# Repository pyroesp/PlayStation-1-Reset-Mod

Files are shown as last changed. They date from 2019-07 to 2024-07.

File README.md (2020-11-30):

# PlayStation 1 Reset Mod  

PlayStation 1 controller combination reset mod.  
This mod when installed, allows you to reset your PlayStation through a button combination on the controller port 1.  

**Checkout the Wiki for more information.**

Disclaimer
----------  
Anyone contributing to this mod is in no way responsible to whatever happens to your PlayStation 1 after installing or removing it.  
You do this at your own risk.  
If you don't know what you're doing, go to someone that does.   

Do **NOT** reset whilst you're saving data. If you do, you'll most likely corrupt your game save and/or your memory card.  
You have been warned.    

Why
-------
Because I have a PSIO from Cybdyn System and there's no way to change games or get back into the PSIO menu system without resetting the PlayStation.  

Versions
--------

* V1.2: Added support for the xStation reset (long reset pulse)  
* V1.1: Fixed incorrect I/O  
* V1.0: First release  

How does it work
----------------
The PlayStation sends commands to the controller and the controller responds with the status of the buttons and joysticks.  
The command and data is read by the microcontroller and after some checks to see if the button combo has been pressed, it will reset the PlayStation.  
The communication is almost exactly like SPI, which is why I'm using it in the later versions of the mod.  

The button combination for the controllers is:  
- L2 + R2 + SELECT + START, for a short reset pulse  
- L2 + R2 + SELECT + CROSS, for a long reset pulse, since V1.2  

The lightgun combination is:
- A + B + TRIGGER, for a long reset pulse 

\***Note:** My mod is connected to controller port 1, but it can be adapted to also work with port 2.  

Tests
----- 
I have successfully tested this with a digital controller, a GUNCON and an analog controller.  

Schematic and PCB
-----------------
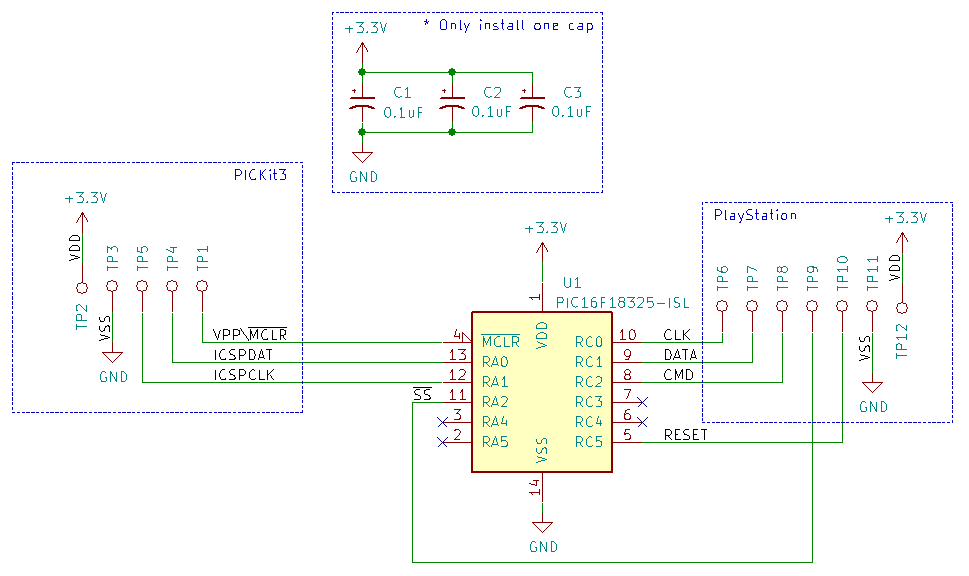
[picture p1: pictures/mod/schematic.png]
schematic
  

PCB is 14.5mm x 12mm, see images below.  
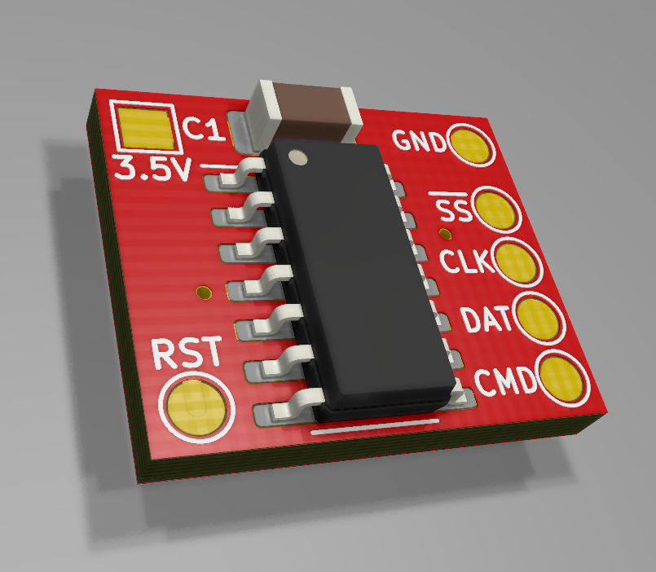
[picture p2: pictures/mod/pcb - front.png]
pcb front
  
 
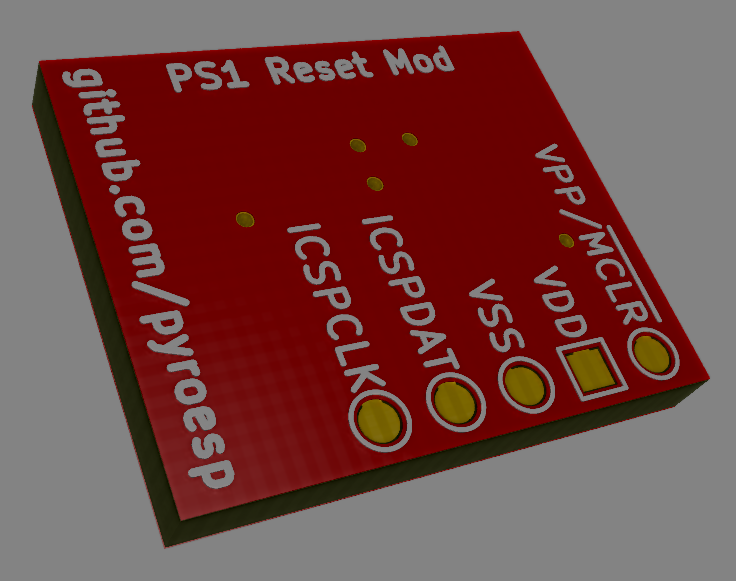
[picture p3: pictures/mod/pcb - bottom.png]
pcb back
  
You can choose from three different cap sizes: 1206, 0805 and 0603.

Parts list
----------
Only two components needed for this mod: the microcontroller and **one** capacitor.  
\***Note:** Digikey links are for reference. Go to your electronics supplier of choice.  
1x [16F18325; 14-SOIC package](https://www.digikey.be/product-detail/en/microchip-technology/PIC16F18325-I-SL/PIC16F18325-I-SL-ND/5323625)  
1x [0.1µF 16V; 1206](https://www.digikey.be/product-detail/en/w-rth-elektronik/885012208030/732-8097-1-ND/5454724) **or** [0.1µF 16V; 0805](https://www.digikey.be/product-detail/en/w-rth-elektronik/885012207045/732-8045-1-ND/5454672) **or** [0.1µF 16V; 0603](https://www.digikey.be/product-detail/en/samsung-electro-mechanics/CL10B104KO8NNNC/1276-1005-1-ND/3889091) package  

\***Note:** Capacitor smd sizes:
* 1206 = 0.125 in × 0.06 in | 3.2 mm × 1.6 mm  
* 0805 = 0.080 in × 0.05 in | 2.0 mm × 1.25 mm
* 0603 = 0.060 in × 0.03 in | 1.6 mm × 0.8 mm

If you don't have a lot of experience soldering I recommend going for the 1206.

Youtube
-------
Proof of concept of the first version: https://www.youtube.com/watch?v=H-n-7R_S09U  
Final proof of concept of the first version: https://www.youtube.com/watch?v=lb_uCGyv6pY  

See also [an 8 part video playlist](https://www.youtube.com/playlist?list=PLGaX4WJGgdHiliTw9mCHme-9vNLV6fG6E) where I go from the Arduino Nano to a PIC16F18325 and a schematic with PCB.  

Three controllers programmed  
----------------------------
Digital, Analog and GUNCON controllers have been programmed.  

/* Controller ID */  
#define ID_DIG_CTRL 0x5A41 // digital  
#define ID_ANP_CTRL 0x5A73 // analog/pad  
#define ID_ANS_CTRL 0x5A53 // analog/stick  
#define ID_GUNCON_CTRL 0x5A63 // light gun  

License
-------
Attribution-ShareAlike 4.0 International, see license file for more info

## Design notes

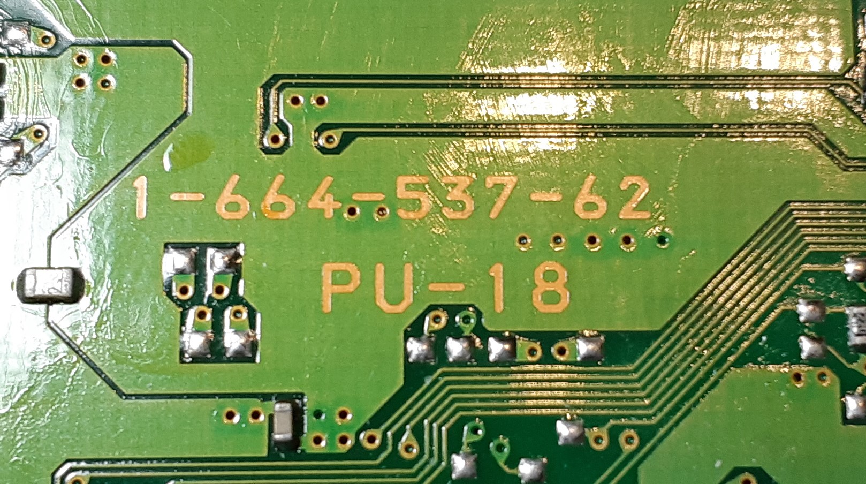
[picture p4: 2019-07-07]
pictures/motherboard/motherboard model.jpg

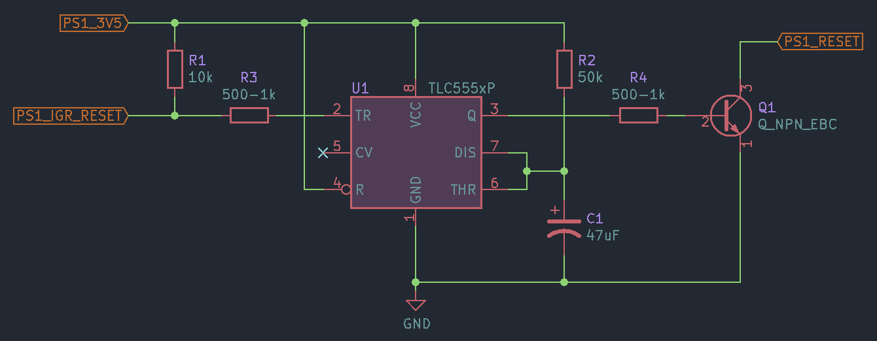
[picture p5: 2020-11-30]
pictures/pulse extender/pulse extender.PNG

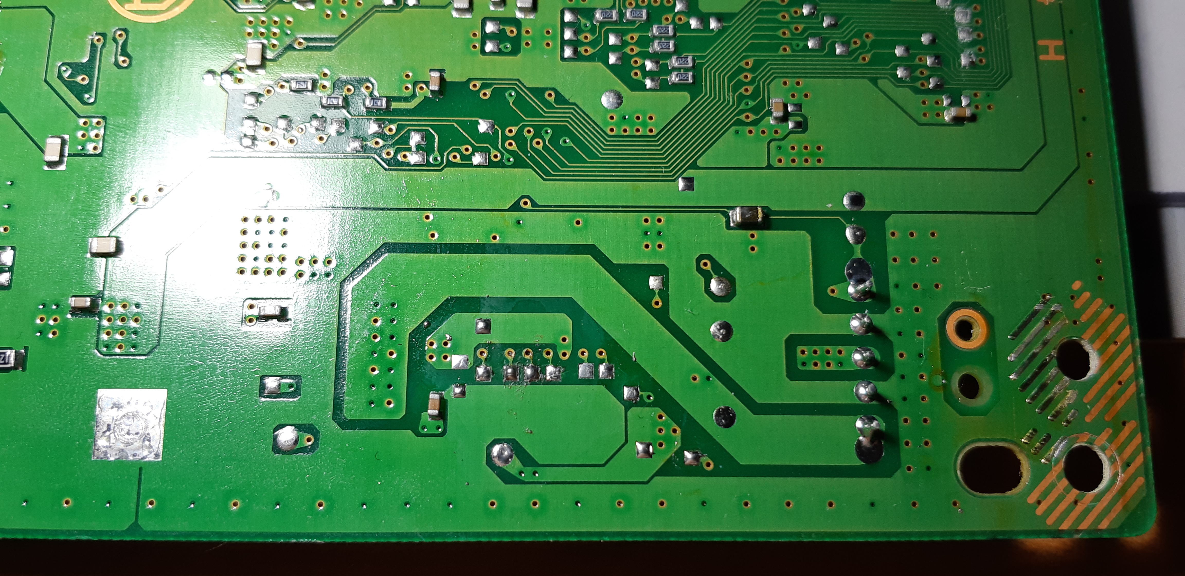
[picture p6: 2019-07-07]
pictures/motherboard/controller connection.jpg

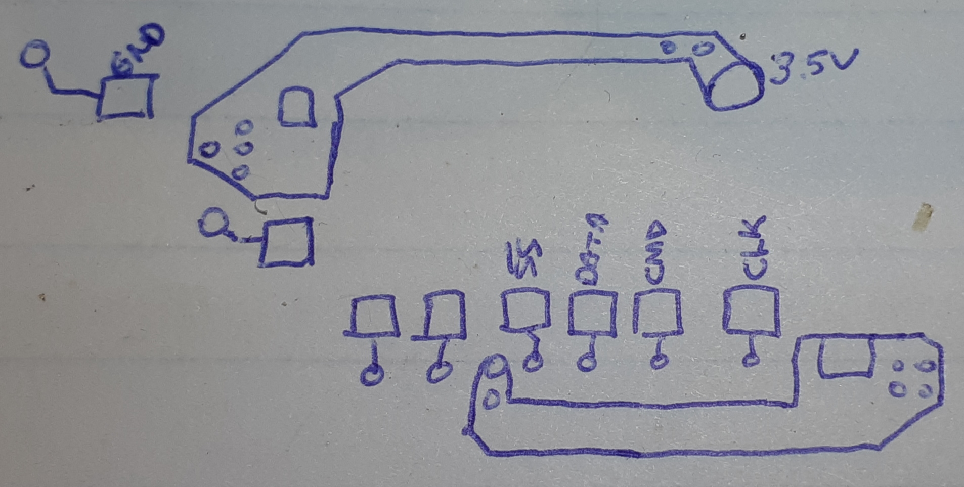
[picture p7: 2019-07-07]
pictures/motherboard/controller connection 2.jpg

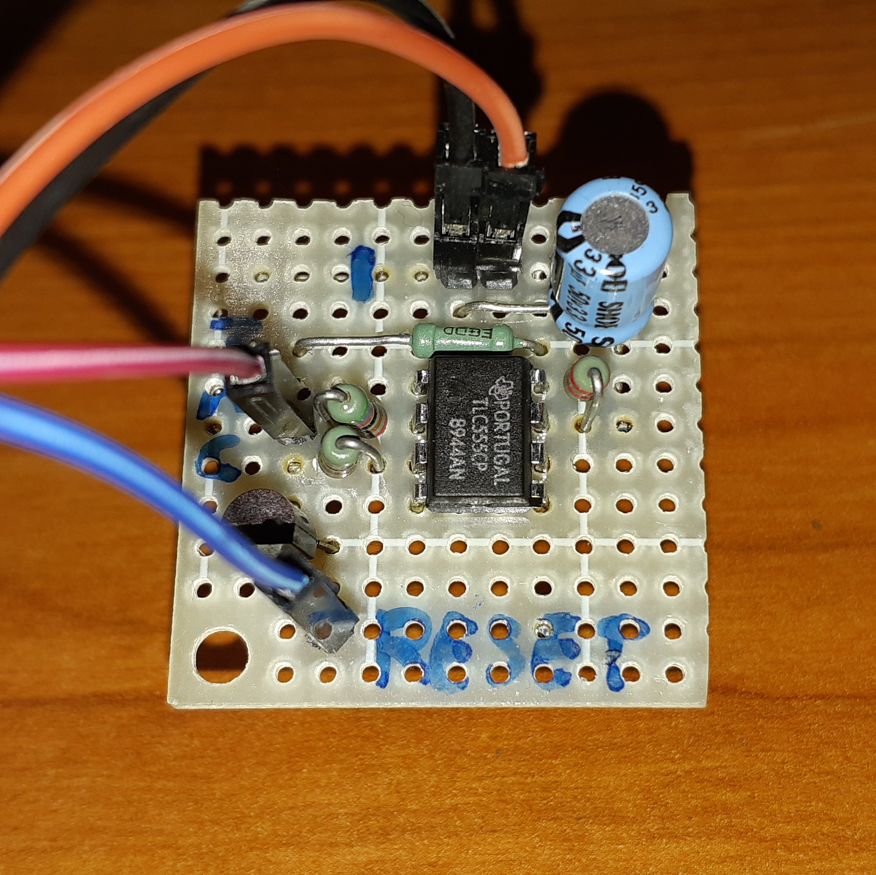
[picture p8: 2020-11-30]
pictures/pulse extender/pulse extender pcb.jpg

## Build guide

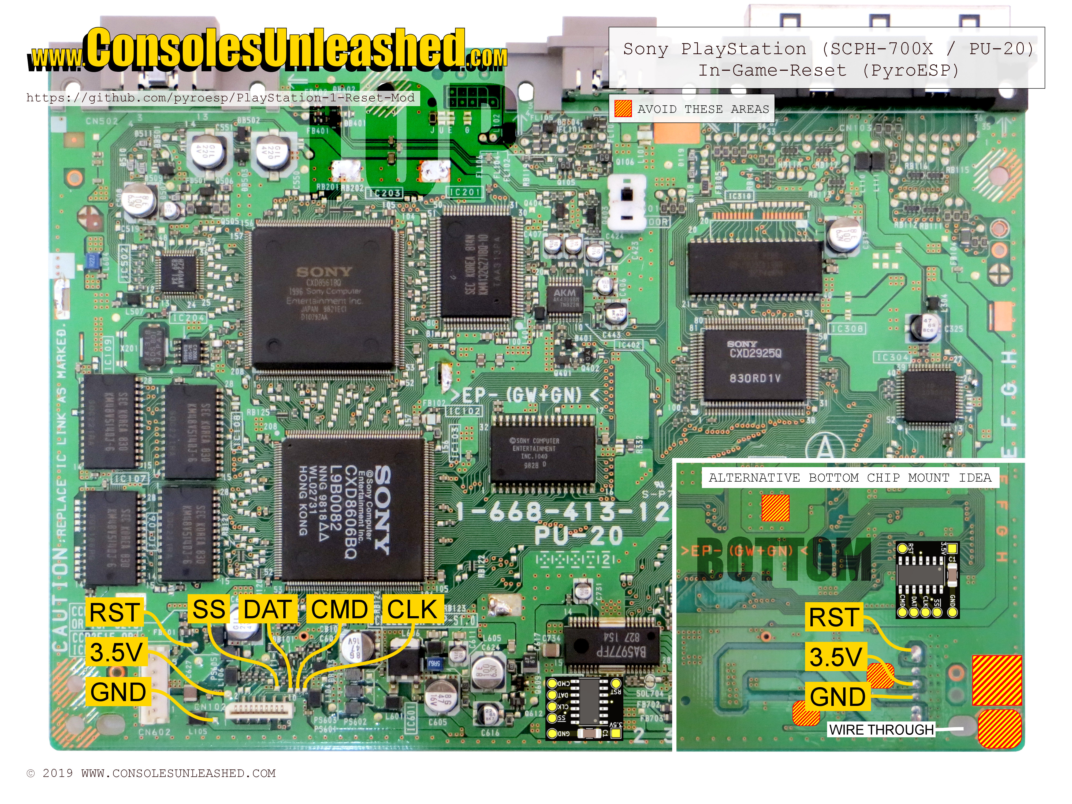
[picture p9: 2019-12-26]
pictures/guide/playstation-igr-scph-700x-pu-20.jpg

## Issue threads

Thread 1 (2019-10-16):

PCB cap and res

pyroesp, 2019-10-16:
There's no silkscreen for either the cap or resistor.
Board is small but there should be a distinction between the cap and the res otherwise people might solder the cap where the res should go.

pyroesp, 2019-10-18:
See also issue #5
Might be able to remove the resistor due to internal pull-up.

pyroesp, 2019-10-19:
fix_pcb branch fixes this issue

Closed 2019-10-19.

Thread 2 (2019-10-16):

Cosmetic change of ICSP GND to VSS

pyroesp, 2019-10-16:
Change ICSP GND silkscreen to VSS to match the schematic and the PICKit 3 pinouts.

pyroesp, 2019-10-19:
fix_pcb branch fixes this issue

Closed 2019-10-19.

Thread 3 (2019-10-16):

Add PlayStation label to schematic

pyroesp, 2019-10-16:
The PICKit 3 rectangle has a label PICKit3.
Do the same for the PlayStation connections.

pyroesp, 2019-10-19:
fix_pcb branch fixes this issue

Closed 2019-10-19.

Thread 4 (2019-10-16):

Guide to know where to solder each point

pyroesp, 2019-10-16:
At the moment, the only guide there is is in the pictures folder and is for a PU-18 motherboard.

Either make a guide for :
- Where to solder on all different PlayStation 1 motherboards.
- How to find the location to solder the mod onto.

**1st option:**
- Clear location with pictures of all different boards
- Need outside help or donor boards to get this

**2nd option:**
- Very basic multimeter skill necessary
- No need for outside help or donor boards
- Prone to user error

pyroesp, 2019-10-16:
From the 2nd option and outside help, option 1 could be made...

pyroesp, 2019-10-16:
For option 1, pictures and annotation of solder points are needed for following motherboards:
- PU-7
- PU-8
- PU-18
- PU-16
- PU-20
- PU-22
- PU-23 ?

Damn-Deal-Done, 2019-11-25:
Hello.

I have made guides for all these now (PU-8/PU-18/PU-20/PU-22). Easy to follow high resolution images. I worked most of today taking apart my PlayStations, taking high resolution photos, and probing with my multimeter. I just want to neaten up the images and I can share them with you. Probably tomorrow.

Is your board layout finalised now?

Are you able to release a Hex with all the fuses pre-programmed for programmers like the TL866?

Would it be possible for you to send me a board for testing?

Much appreciated.

Damn-Deal-Done, 2019-11-26:
Hi.

I have uploaded them to my Github. https://github.com/Damn-Deal-Done/playstation-in-game-reset-solder-points

They have my branding. Let me know if you want some without.

Not tested the guides, but all the points have continuity to the correct controller pins.

I can get a few made and test all these installs, but only once your board is finalised.

Cheers

pyroesp, 2019-11-28:
Those look really good! Awesome, thanks!
I'll make a copy off the images to put in my repository, so I have them too.
I'll have to add Credits to my readme :D
Will do this later today.

Thanks again.

Damn-Deal-Done, 2019-11-28:
No problem. I can do PU-23 later today. I don't have PU-7 or PU-16 but will do them if they cross my path for an install.

Once the chips arrive in a week or two, I will test and work out the best placement for the modboard and update the images.

Got my PICkit4 coming today.

pyroesp, 2019-11-28:
I have a PICKit3 but it shouldn't be too different than a PICKit4 so if you need any help with it, you can PM me on twitter over the weekend or in the evening in the week and I'll help you get setup.

Damn-Deal-Done, 2019-11-28:
Cheers. I think I managed.

Installed MPLAB X IPE and everything was straight forward.

Programmed the chip in an adapter plugged into a breadboard. Powered chip with the PICkit4. It was detected, successfully programmed and verified. :)

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

hurda, 2020-04-24:
I made a guide for PU-23 using a service-manual, but the mainboard-pics I used are from Wikipedia.
https://commons.wikimedia.org/wiki/File:Sony_Playstation_1_SCPH-9002_motherboard_top.jpg
https://commons.wikimedia.org/wiki/File:Sony_Playstation_1_SCPH-9002_motherboard_bottom.jpg
I don't know how to properly follow the requirements of the CC-license there.

pyroesp, 2020-04-24:
Hey thanks for that, no worries.
I know this mod works on all PS1 but I don't know if it's really useful to have it on a PS1 that doesn't have a parallel port / PSIO device.

If you want to post the pictures, add a link to CC BY-SA 4.0 license, say it's from wikipedia and add the link to the wiki images. I think you also want to say you modified the image.
That's pretty much it I think.

Damn-Deal-Done, 2020-04-24:
I made a PU-23 a few months ago. Just uploaded it. By all means make one if you still want. But mine is here and it matches the others. https://github.com/Damn-Deal-Done/playstation-in-game-reset-solder-points. No license needed.

Handy for rage quitters. :)

Cheers

hurda, 2020-04-25:
> I made a PU-23 guide a few months ago. Just uploaded it. By all means make one if you still want. But mine is here and it matches the others. https://github.com/Damn-Deal-Done/playstation-in-game-reset-solder-points. No license needed.

Ok, yours is better. :)
Except for one thing: There's a nice soldering-testpoint for DAT just below the controller-connector left of the "CN102"-marking. The rightmost one in the group of three.
Or at least that one should be for DAT according to the service-manual.

Damn-Deal-Done, 2020-04-25:
Cheers. Will have a look. I checked them all for continuity, but I have the most garbage multimeter imaginable.

Damn-Deal-Done, 2020-04-27:
Cheers, that was correct. Image is now updated using the test point for DAT. I am officially blaming my tools.

hurda, 2020-04-28:
You uploaded the old image again. ;)

Damn-Deal-Done, 2020-04-28:
That is correct. I need to start getting more sleep. Reuploaded.

pyroesp, 2020-12-21:
PU-23 has been added, finally.

Closed 2020-12-29.

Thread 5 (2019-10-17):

Pull-up resistor on MCLR needed ?

pyroesp, 2019-10-17:
From chapter 12.2.7 WEAK PULL-UP CONTROL in the 16F18325:
> PORTA pin RA3 includes the MCLR/VPP input. The
MCLR input allows the device to be reset, and can be
disabled by the MCLRE bit of Configuration Word 2. A
weak pull-up is present on the RA3 port pin. This weak
pull-up is enabled when MCLR is enabled (MCLRE = 1)
or the WPUA3 bit is set.

Is the external pull-up needed for PICKit3?
If not, then remove resistor.

pyroesp, 2019-10-19:
Removed the pull-up resistor from the breadboard this morning and everything seems to be working fine.
Once the resistor is out of the schematic and pcb, this issue can be closed.

pyroesp, 2019-10-19:
fix_pcb branch fixes this issue

Closed 2019-10-19.

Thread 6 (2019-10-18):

Printing PCB

ijacquez, 2019-10-18:
Would these be the right options to print a few PCBs?

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

Attached is the [GERBER files](https://github.com/pyroesp/PlayStation-1-Reset-Mod/files/3745094/GERBER.zip).

pyroesp, 2019-10-19:
I don't have all those options when I go for the PCB prototype quote.

This is what I'm going for :
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

pyroesp, 2019-10-19:
Make sure you get the latest version which will hide the JLCPCB order number.
Also, the resistor is gone as it's not needed due to internal pull-up, see #5 .

ijacquez, 2019-10-20:
Thanks, I'll update.

The 3.5V has changed as well. Will a part list be given as well?

pyroesp, 2019-10-20:
I'll either add the part list to the readme or add it to a wiki.

pyroesp, 2019-10-20:
I've added a part list to the readme after the schematic and pcb images.

You need anything else ?

ijacquez, 2019-10-20:
Thank you. I'll order a batch and make a few to test them out.

I guess for future revisions, it would be nice to have a connector of sorts for the PICkit3

I'll have to see what motherboard I have.

I have a PS3 to PSX adapter, so I'll see if it works.

Thanks.

pyroesp, 2019-10-20:
@ijacquez : A connector would add cost for a one time thing.
Best way I see how to do it is make your own cable with pogo pins, that's how I'm going to make it.

If the PS3 controller works on the PS1 with that adapter, then that adapter must be "translating" the communication to the PS1 protocol, which means that it should work if the device ID is one of the three programmed in the code.

ijacquez, 2019-11-10:
Got the PCB, soldered the chip, the cap.

Programming required that I power it through USB (v2.3). That threw me for a loop. I can only at this point erase, program, check blank, and verify. All passed.

What is a good way to test this without directly connecting to the PlayStation?

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

pyroesp, 2019-11-12:
Yes for programming, you need to supply the board with voltage.
You'd do that from the pickit 3 programming menu. Probably something I need to add to the readme!

If you want to test the board I would suggest making a test program for it.
There is no way to test the board out of the PlayStation unfortunately.

ijacquez, 2019-11-12:
I have made a fairly big mistake with programming the chip.

So when the board needs to be supplied with voltage, does that mean I simply connect the PICkit3's VPP to VDD, then within the programming menu, have the PICkit3 supply the voltage, and set the voltage to ~2.5V?

pyroesp, 2019-11-14:
No, the VPP of the PICKit3 goes to the VPP/MCLR pin on the back. VPP outputs a higher voltage than VDD when programming, which potentially could damage the PIC microcontroller!

The silkscreen on the back should mention this :
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

In the advanced mode of MPLAB IPE go to the Power tab. These are my parameters for the 16F18325:
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
These parameters should have a default value for the 16F18325, but the thing you might have to check is the usage of high voltage programming and also that checkbox for powering the target with the PICKit3.
The VDD voltage can be either 5V or 3.5V, it doesn't really matter as long as you're programming the PIC when it's not connected to the PlayStation.

Once it is programmed and verified by MPLAB IPE, then you only need to install it in the PlayStation.

pyroesp, 2019-12-14:
@ijacquez hello, just letting you know that there's a new firmware version available.
https://github.com/pyroesp/PlayStation-1-Reset-Mod/releases/tag/v1.1

There was an error while making the PCB where data and cmd were switched. The new firmware fixes this.
Gerber files are still the same as in v1.0

ijacquez, 2019-12-15:
Thanks for the heads up. I'll give the project another whirl.

pyroesp, 2020-02-14:
Since there's nothing new here I'll close this issue.

Closed 2020-02-14.

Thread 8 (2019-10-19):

Hide JLCPCB order number

pyroesp, 2019-10-19:
JLCPCB puts the order number on the PCB. There's no way around that. Find a place to hide it if possible.

pyroesp, 2019-10-19:
You can specify the location of the jlcpcb order by adding JLCJLCJLCJLC somewhere on the silkscreen.
I've added it underneath the microcontroller so that it is hidden.

Commit 2d62dcc updated the pcb and gerber files.

Closed 2019-10-19.

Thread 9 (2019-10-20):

Code clean-up

pyroesp, 2019-10-20:
Clean up the code for first release:
- Add a debug define for uart debugging
- remove RA4 and RA5 pin toggle
- move functions below main and add function prototypes
- fix tab/space indents

pyroesp, 2019-10-20:
Commit 7637368 fixed the code for a first release

Closed 2019-10-20.

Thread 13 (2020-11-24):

Alternative button-combo for longer reset

ArcadeTV, 2020-11-24:
Thank you very much for this great project, great documentation and dedication to this!

I would like to suggest adding a second button-combo to the code, which when triggered holds the reset for appx. 2 seconds.
The reason for this is the release of the X-Station optical drive emulator, which is responding to the longer reset and returning to the menu instead of resetting the game. There's a IGR for the snes which works as described when using an sd2snes/fxPAKpro.

pyroesp, 2020-11-24:
Looking at the xStation doc it looks like it needs "about 3 seconds" to go back to the menu.
I could definitely add something like that.

ArcadeTV, 2020-11-25:
On the SNES the IGR uses a similar combo:
(https://github.com/borti4938/SNES_MultiRegion_with_DeJitter_QID)

simple reset: L + R + Select + Start
double reset (back to main menu of sd2snes): L + R + Select + X

Since the layout of the PS1 controller is similar to the snes, I'd suggest this combo for the change.

Thank you very much for even considering adding this, it's very much appreciated!

pyroesp, 2020-11-25:
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
Yeah, I was thinking about using the x button too, instead of START, for the longer reset.
Press x for xStation reset. It's the perfect button for it.

> Thank you very much for even considering adding this, it's very much appreciated!
No worries! When I talked about the xStation online and compatibility with my mod, people told me that they'd most likely also buy the PS1Digital so mine wouldn't be needed.
From then on I never really paid much more attention to this, but I'm not against adding features like this to the mod.

It only takes a minute to change the code, but I'll have to test this to see if it works as intended.
Hopefully I can spare some time to do this this weekend.

If not then you'll see it when I close this issue and/or post about it online.

ArcadeTV, 2020-11-25:
No stress, take your time. I can test too once you pushed the changes. I might have a PIC16F18325 laying around.
Thank you very much again for this!

pyroesp, 2020-11-30:
After a bit of testing I've commited the new code for the PIC microcontroller.
The xStation should be supported now.

492eb7d

Damn-Deal-Done, 2020-11-30:
ArcadeTV if you want to test a board with the new firmware just let me know and I can send you one for free. It's not a problem.

ArcadeTV, 2020-11-30:
> ArcadeTV if you want to test a board with the new firmware just let me know and I can send you one for free. It's not a problem.

That's so nice, thank you! I have a breakout board for testing, also ordered a pcb with my latest jlcpcb order ;-)

Closed 2020-11-30.

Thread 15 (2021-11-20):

Programing the PIC16F18325

mroy1300, 2021-11-20:
Hello,

I'm trying to program the PIC16F18325 with the supplied hex file but when I read the device memory the hex that gets output is different from the original. Am I doing something wrong? How are you supposed to verify that the chip was successfully programed?

My apologies if this is not the best place to post this but I didn't know where else to do it.

Let me know if you need any additional info, I didn't know what info I should supply.

pyroesp, 2021-11-21:
It should be identical to the hex. I'm not doing anything fancy to program it.
You can check the "how to" in the wiki.

Also try another 16F18325 just in case that one is doing weird things.

mroy1300, 2021-11-21:
I have been doing more testing and I found that a fresh non-programed chip output the same hex file as a programed chip. I'm wondering if the programmer is either not programing the chip or if I'm reading the hex file wrong.

I have attached pictures of the chip, board, and programer. The VDD, VPP, CLK, VSS, and DAT pads are out of order on the board so I made a jumper to correct that.

I also took a video of the process. It looks like the hex file is not being written to the chip. I'm pretty good with computers but this is my first attempt at programing microchips. Hopefully I'm just doing something wrong.

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

https://user-images.githubusercontent.com/94731368/142781816-cbd6bbb6-b071-4ef7-b262-45f8858fef55.mp4

pyroesp, 2021-11-22:
When programming through IPE, you can see the output saying "Program/Verify completed". Which means it's programmed and verified the contents of the chip.
If you want to read the data back, you can just click on the read button instead of going to the IDE.

Also, you are selecting EE/Flash data instead of device memory in the IDE.

mroy1300, 2021-11-22:
I see the log saying it's verified but the hex doesn't change. I have read Device memory through IDE also but I get a huge hex file with 1061 lines so I figured that was reading the memory from the programmer.

When I read through the IPE I don't get any output besides the IPE saying it was read. DO I need to turn on logging?
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

My apologies, I assume I'm doing something wrong. I just can't figure it out.

mroy1300, 2021-11-23:
OK, I have it so that I can read and export the hex file in IPE. When I program the chip everything looks right and I even ran a blank check on the chip. The program confirmed that the chip is not blank but when I read the hex file it has not changed. I also confirmed that the board does not work when installed into the PS1. I'm at a loss at this point. Everything seems like it should be working.

pyroesp, 2021-11-23:
I suggest you try programming a blinky LED to another microcontroller to see if your setup works.

Closed 2021-12-04.

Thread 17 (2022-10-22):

WTF???

orabeidm, 2022-10-22:
i ordered 2 controllers, my friend flashed them and i installed them in pu22 - none work. Next, I decided to make a mod using arduino, but the code presented here is not for the Arduino IDE. OK. trying to build it with avr toolchain and then flash it with avrdude - not going to. in the code there is a call to the port, which is not physically present in MK 328p. in 328p there are pins that sit on ports B, C and D, and in the source there is a setting for port E pins.

wtf???

is it working at all? is there any way to make this work? I have no way to buy a ready-made mod. there is no delivery to my country.

orabeidm, 2022-10-22:
I'm stupid, I mixed up the wires

Closed 2022-10-22.

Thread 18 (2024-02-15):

IGR for both Controller Ports

GeAd23, 2024-02-15:
Is it possible to use two IGR boards for Controller 1 and 2. How can I do this ? (Modchip is installed too)

I would use one igr from (flat) unleashedmods and a normal igr board.

Yours Sincerely

pyroesp, 2024-02-19:
Hi sorry for the late reply.
Each port has it's own ATT (or SS) signal as seen here on port 1:
https://raw.githubusercontent.com/pyroesp/PlayStation-1-Reset-Mod/master/pictures/guide/playstation-controller-pin-map.jpg

IGR1 should connect to ATT1 and IGR2 should connect to ATT2 if I'm not mistaken.

GeAd23, 2024-02-19:
Okay. Thank you. The other ports are connected together Else SS ? Like SPI work.
I would test it out.

Yours Sincerely

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

Closed 2024-02-21.

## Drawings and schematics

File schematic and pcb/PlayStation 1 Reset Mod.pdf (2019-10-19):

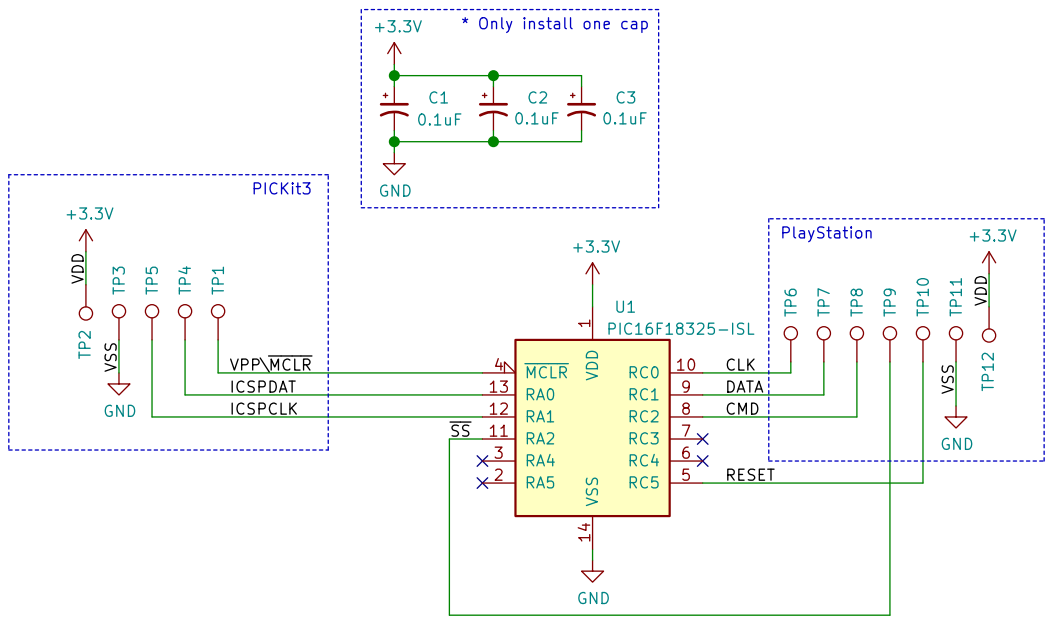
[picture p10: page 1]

* Only install one cap
+3.3V GND

File: PlayStation 1 Reset Mod.sch Sheet: /
Id: 1/1 Title:

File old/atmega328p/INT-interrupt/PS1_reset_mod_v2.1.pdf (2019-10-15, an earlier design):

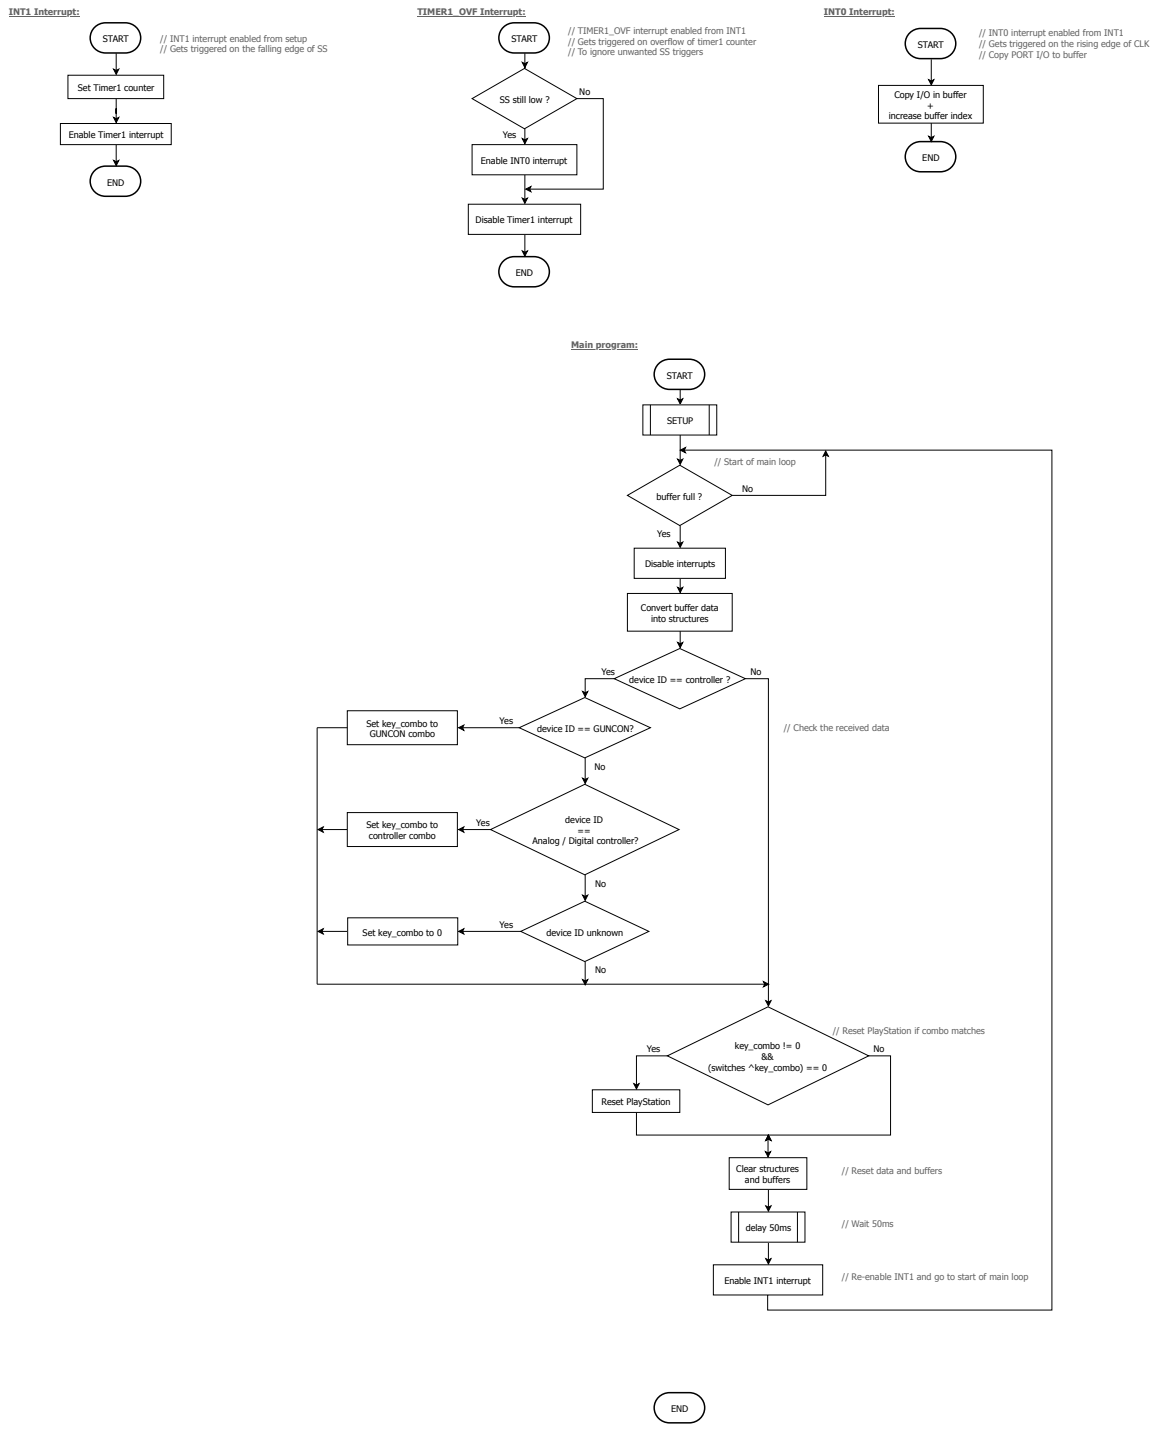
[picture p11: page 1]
START; END; Enable Timer1 interrupt; SETUP; buffer full ?; Disable interrupts; device ID ==; Set key_combo to GUNCON combo; Set key_combo to controller combo; Set key_combo to 0; key_combo != 0 && (switches ^key_combo) == 0; Reset PlayStation; Clear structures and buffers; Yes; // Wait 50ms; delay 50ms; INT1 Interrupt:; INT0 Interrupt:; Main program:; Enable INT0 interrupt; TIMER1_OVF Interrupt:; Set Timer1 counter; Disable Timer1 interrupt

// INT1 interrupt enabled from setup
// Gets triggered on the falling edge of SS

// TIMER1_OVF interrupt enabled from INT1
// Gets triggered on overflow of timer1 counter
// To ignore unwanted SS triggers

// INT0 interrupt enabled from INT1
// Gets triggered on the rising edge of CLK
// Copy PORT I/O to buffer

Copy I/O in buffer

SS still low ?

increase buffer index

// Start of main loop

Convert buffer data
into structures

Yes
device ID == controller ?

device ID == GUNCON?

// Check the received data

Analog / Digital controller?

device ID unknown

// Reset PlayStation if combo matches

// Reset data and buffers

// Re-enable INT1 and go to start of main loop Enable INT1 interrupt

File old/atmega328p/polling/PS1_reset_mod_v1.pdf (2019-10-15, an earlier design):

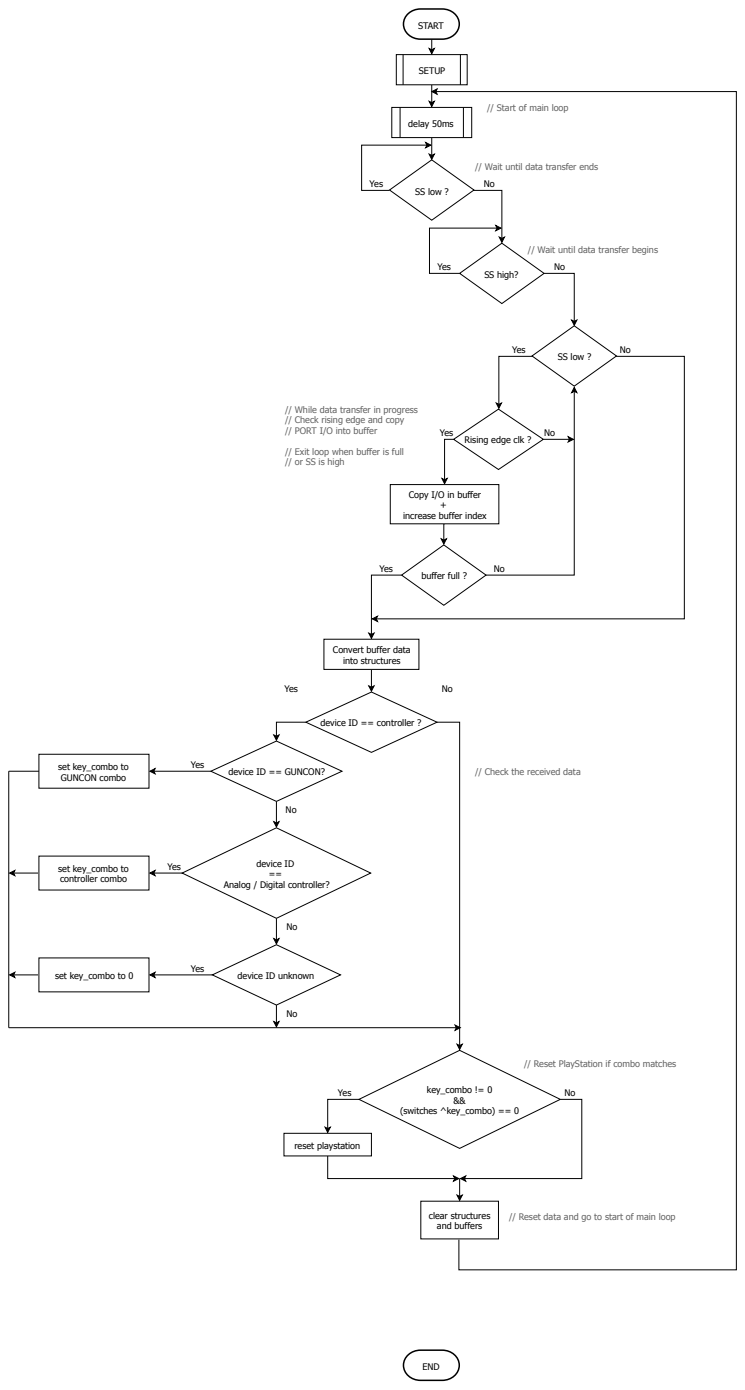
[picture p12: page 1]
START; SETUP; delay 50ms; SS low ?; Yes; SS high?; buffer full ?; device ID ==; set key_combo to GUNCON combo; set key_combo to controller combo; set key_combo to 0; key_combo != 0 && (switches ^key_combo) == 0; reset playstation; clear structures and buffers; END

// Start of main loop

// Wait until data transfer ends

// Wait until data transfer begins

// While data transfer in progress
// Check rising edge and copy
// PORT I/O into buffer

Yes
Rising edge clk ?

// Exit loop when buffer is full
// or SS is high

Copy I/O in buffer

increase buffer index

Convert buffer data
into structures

device ID == controller ?

device ID == GUNCON?

// Check the received data

Analog / Digital controller?

device ID unknown

// Reset PlayStation if combo matches

// Reset data and go to start of main loop

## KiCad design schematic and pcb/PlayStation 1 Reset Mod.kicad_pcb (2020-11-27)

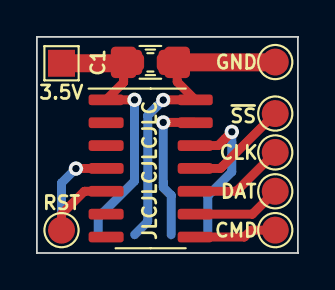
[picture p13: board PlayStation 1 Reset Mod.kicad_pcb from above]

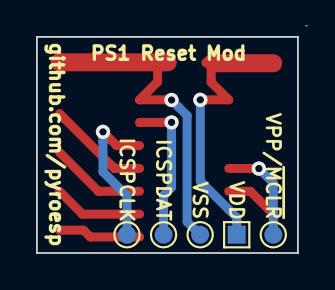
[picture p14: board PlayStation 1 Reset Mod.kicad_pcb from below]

Board: 2 copper layers, 14.5 x 12.0 mm, 15 parts (5 on the bottom side), 9 nets.

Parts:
3.5V: TestPoint; TestPoint_Pad_1.5x1.5mm
C1: 0.1uF; C_1206_3216Metric_Pad1.42x1.75mm_HandSolder
C2: 0.1uF; C_0805_2012Metric_Pad1.15x1.40mm_HandSolder
C3: 0.1uF; C_0603_1608Metric_Pad1.05x0.95mm_HandSolder
CLK: TestPoint; TestPoint_Pad_D1.5mm
CMD: TestPoint; TestPoint_Pad_D1.5mm
DAT: TestPoint; TestPoint_Pad_D1.5mm
GND: TestPoint; TestPoint_Pad_D1.5mm
ICSPCLK: TestPoint; TestPoint_Pad_D1.0mm
ICSPDAT: TestPoint; TestPoint_Pad_D1.0mm
RST: TestPoint; TestPoint_Pad_D1.5mm
U1: PIC16F18325-ISL; SOIC-14_3.9x8.7mm_P1.27mm
VDD: TestPoint; TestPoint_Pad_1.0x1.0mm
VPP/~MCLR: TestPoint; TestPoint_Pad_D1.0mm
VSS: TestPoint; TestPoint_Pad_D1.0mm

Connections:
+3V3: 3.5V.1, C1.1, C2.1, C3.1, U1.1, VDD.1
/CLK: CLK.1, U1.10
/CMD: CMD.1, U1.8
/DATA: DAT.1, U1.9
/ICSPCLK: ICSPCLK.1, U1.12
/ICSPDAT: ICSPDAT.1, U1.13
/RESET: RST.1, U1.5
/VPP\~MCLR: U1.4, VPP/~MCLR.1
GND: C1.2, C2.2, C3.2, GND.1, U1.14, VSS.1

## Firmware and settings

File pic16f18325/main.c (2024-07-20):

/*
 * File:   main.c
 * Author: pyroesp
 * 
 * PlayStation 1 Reset Mod for PIC16F18325
 *
 * Created on September 21, 2019, 5:33 PM
 
 Connection:
    RA2 = SS
    RC0 = CLK
    RC1 = DATA
    RC2 = CMD
    SDO1,2 = unassigned
    RC5 = RESET
 */


// CONFIG1
#pragma config FEXTOSC = OFF     // FEXTOSC External Oscillator mode Selection bits (HS (crystal oscillator) above 4 MHz)
#pragma config RSTOSC = HFINT32 // Power-up default value for COSC bits (HFINTOSC with 2x PLL (32MHz))
#pragma config CLKOUTEN = OFF   // Clock Out Enable bit (CLKOUT function is disabled; I/O or oscillator function on OSC2)
#pragma config CSWEN = ON       // Clock Switch Enable bit (Writing to NOSC and NDIV is allowed)
#pragma config FCMEN = OFF      // Fail-Safe Clock Monitor Enable (Fail-Safe Clock Monitor is disabled)

// CONFIG2
#pragma config MCLRE = ON       // Master Clear Enable bit (MCLR/VPP pin function is MCLR; Weak pull-up enabled)
#pragma config PWRTE = OFF      // Power-up Timer Enable bit (PWRT disabled)
#pragma config WDTE = OFF       // Watchdog Timer Enable bits (WDT disabled; SWDTEN is ignored)
#pragma config LPBOREN = OFF    // Low-power BOR enable bit (ULPBOR disabled)
#pragma config BOREN = OFF      // Brown-out Reset Enable bits (Brown-out Reset disabled)
#pragma config BORV = LOW       // Brown-out Reset Voltage selection bit (Brown-out voltage (Vbor) set to 2.45V)
#pragma config PPS1WAY = ON     // PPSLOCK bit One-Way Set Enable bit (The PPSLOCK bit can be cleared and set only once; PPS registers remain locked after one clear/set cycle)
#pragma config STVREN = OFF     // Stack Overflow/Underflow Reset Enable bit (Stack Overflow or Underflow will not cause a Reset)
#pragma config DEBUG = OFF      // Debugger enable bit (Background debugger disabled)

// CONFIG3
#pragma config WRT = OFF        // User NVM self-write protection bits (Write protection off)
#pragma config LVP = OFF        // Low Voltage Programming Enable bit (High Voltage on MCLR/VPP must be used for programming.)

// CONFIG4
#pragma config CP = OFF         // User NVM Program Memory Code Protection bit (User NVM code protection disabled)
#pragma config CPD = OFF        // Data NVM Memory Code Protection bit (Data NVM code protection disabled)

// #pragma config statements should precede project file includes.
// Use project enums instead of #define for ON and OFF.

#define _XTAL_FREQ 32000000

#include <xc.h>
#include <stdint.h>

#define _BV(b) (1<<(b))

/* Uncomment the define below to have UART TX debugging on RC3 */
//#define DEBUG

#ifdef DEBUG
#define REBOOT_DELAY 2 // s
#else
#define REBOOT_DELAY 20 // s
#endif

#define SHORT_DELAY 500 // ms
#define LONG_DELAY 2 // s

/* Reset port */
#define PS1_LAT_IO LATC // IO port reg used for RESET
#define PS1_TRIS_IO TRISC // IO dir reg used for RESET
#define PS1_RESET 5 // Only IO that outputs a logic 0

/* Controller ID */
#define ID_DIG_CTRL 0x5A41 // digital: SCPH-1080 (EU)
#define ID_ANP_CTRL 0x5A73 // analog/pad: SCPH-110 (EU)
#define ID_ANS_CTRL 0x5A53 // analog/stick: SCPH-110 (EU)
#define ID_DS2_CTRL 0x5A79 // dualshock 2
#define ID_GUNCON_CTRL 0x5A63 // light gun: NPC-103 (EU)

/* PlayStation Commands */
#define CMD_SEL_CTRL_1 0x01 // select controller 1
#define CMD_SEL_MEMC_1 0x81 // select memory card 1
#define CMD_READ_SW 0x42 // read switch status from controller

/* PlayStation Communication Buff Size */
#define PS1_CTRL_BUFF_SIZE 9 // max size of buffer needed for a controller

/* Key Combo */
#define KEY_COMBO_CTRL 0xFCF6       // select-start-L2-R2   1111 1100 1111 0110
#define KEY_COMBO_GUNCON 0x9FF7     // A-trigger-B          1001 1111 1111 0111
#define KEY_COMBO_XSTATION 0xBCFE   // select-cross-L2-R2   1011 1100 1111 1110

/*
Keys : 
    SELECT, // 0
    L3,
    R3,
    START, // light gun A
    UP,
    RIGHT,
    DOWN,
    LEFT,
    L2,
    R2,
    L1,
    R1,
    TRIANGLE,
    CIRCLE, // light gun trigger
    CROSS, // light gun B
    SQUARE
*/


/* PlayStation Controller Command Union */
union PS1_Cmd{
    uint8_t buff[PS1_CTRL_BUFF_SIZE];
    struct{
        uint8_t device_select; // 0x01 or 0x81
        uint8_t command; // 0x42 for read switch
        uint8_t unused[PS1_CTRL_BUFF_SIZE-2]; // always 0 for controller
    };
};

/* PlayStation Controller Data Union */
union PS1_Ctrl_Data{
    uint8_t buff[PS1_CTRL_BUFF_SIZE]; // buffer to read data
    struct{
        uint8_t unused; // always 0xFF
        uint16_t id; // 0x5Ayz - y = type; z = # of half word
        uint16_t switches; // controller switches
        union{
            // light gun only (8MHz clock counter since hsync)
            uint16_t x_pos; // if 0x0001 then error, check y_pos
            struct{
                uint8_t adc0; // right joy X
                uint8_t adc1; // right joy Y
            };
        };
        union{
            //light gun only (scanlines since vsync)
            uint16_t y_pos; // if x_pos = 0x0001 && y_pos = 0x000A => not aimed at screen
            struct{
                uint8_t adc2; // left joy X
                uint8_t adc3; // left joy Y
            };
        };
    };
};

/* Global variables */
volatile union PS1_Cmd cmd;
volatile union PS1_Ctrl_Data data;
volatile uint8_t cmd_cnt, data_cnt;

/* Function prototype */
void reverse_byte(uint8_t *b);
void clear_buff(uint8_t *p, uint8_t s);
void __delay_s(uint8_t s);

void reset_short(void);
void reset_long(void);

#ifdef DEBUG
void UART_init(void);
void UART_sendByte(uint8_t c);
void UART_print(uint8_t *str);
void UART_printHex(uint8_t b);
#else
#define UART_init(a)
#define UART_sendByte(a) 
#define UART_print(a) 
#define UART_printHex(a) 
#endif


/* Interrupt */
void __interrupt() _spi_int(void) {    
    // SPI1 interrupt
    if (PIR1bits.SSP1IF){
        if (data_cnt < PS1_CTRL_BUFF_SIZE){
            data.buff[data_cnt] = SSP1BUF;
            data_cnt++;
        }
        PIR1bits.SSP1IF = 0; // clear SPI1 flag
    }
    // SPI2 interrupt
    if (PIR2bits.SSP2IF){
        if (cmd_cnt < PS1_CTRL_BUFF_SIZE){
            cmd.buff[cmd_cnt] = SSP2BUF;
            cmd_cnt++;
        }
        PIR2bits.SSP2IF = 0; // clear SPI2 flag
    }
}

/* Main */
void main(void){
    uint8_t i;
    
    // SETUP I/O
    ANSELA = 0; // port A is digital IO
    LATA = 0; // clear latch A
    LATC = 0; // clear latch C
    ANSELC = 0; // port C is digital IO
    
    PS1_LAT_IO &= ~_BV(PS1_RESET); // clear reset output 
    PS1_TRIS_IO |= _BV(PS1_RESET); // set reset pin to input

    TRISAbits.TRISA2 = 1; // SS set to input
    TRISCbits.TRISC0 = 1; // SCK set to input
    TRISCbits.TRISC1 = 1; // SDI1 set to input
    TRISCbits.TRISC2 = 1; // SDI2 set to input
    
    // SETUP SPI1 & SPI2 I/O
    SSP1SSPPSbits.SSP1SSPPS = 0x02; // SS1 = RA2 
    SSP2SSPPSbits.SSP2SSPPS = 0x02; // SS2 = RA2 
    
    SSP1CLKPPSbits.SSP1CLKPPS = 0x10; // SCK1 = RC0
    SSP2CLKPPSbits.SSP2CLKPPS = 0x10; // SCK2 = RC0
    
    SSP1DATPPSbits.SSP1DATPPS = 0x11; // SDI1 = RC1 
    SSP2DATPPSbits.SSP2DATPPS = 0x12; // SDI2 = RC2 
    
    // SETUP SPI1 & SPI2
    SSP1STATbits.SMP = 0; // slave mode SPI1
    SSP1STATbits.CKE = 0; // transmit from idle to active
    SSP1CON1bits.CKP = 1; // clock idle high
    SSP1CON1bits.SSPM = 0x04; // slave mode: clk = sck pin; SS enabled
    SSP1CON3bits.BOEN = 1; // ignore BF flag
    SSP1CON1bits.SSPEN = 1; // enable SPI1
    
    SSP2STATbits.SMP = 0; // slave mode SPI2
    SSP2STATbits.CKE = 0; // transmit from idle to active
    SSP2CON1bits.CKP = 1; // clock idle = high
    SSP2CON1bits.SSPM = 0x04; // slave mode: clk = sck pin; SS enabled
    SSP2CON3bits.BOEN = 1; // ignore BF flag
    SSP2CON1bits.SSPEN = 1; // enable SPI2
    
    SSP1BUF = 0xFF;
    SSP2BUF = 0xFF;
    
    // DEBUG
    UART_init();
    UART_print((uint8_t*)"PlayStation 1 mod:\n\r");
    
    // SETUP variables and arrays
    data_cnt = 0;
    cmd_cnt = 0;
    
    clear_buff((uint8_t*)cmd.buff, PS1_CTRL_BUFF_SIZE);
    clear_buff((uint8_t*)data.buff, PS1_CTRL_BUFF_SIZE);
    
    // delay before enabling interrupts
    __delay_s(REBOOT_DELAY); // wait 20 sec before next reset
    
    // SETUP INTERRUPTS
    PIR1bits.SSP1IF = 0; // clear SPI1 flag
    PIR2bits.SSP2IF = 0; // clear SPI2 flag
    PIE1bits.SSP1IE = 1; // enable MSSP interrupt (SPI1)
    PIE2bits.SSP2IE = 1; // enable MSSP interrupt (SPI2)
       
    INTCONbits.PEIE = 1; // peripheral interrupt enable
    INTCONbits.GIE = 1; // global interrupt enable
       
    // MAIN LOOP
    for(;;){
        if (data_cnt >= PS1_CTRL_BUFF_SIZE || cmd_cnt >= PS1_CTRL_BUFF_SIZE){
            INTCONbits.PEIE = 0; // peripheral interrupt disable
            UART_print((uint8_t*)"\n\rCMD: ");
            for (i = 0; i < PS1_CTRL_BUFF_SIZE; i++){
                reverse_byte((uint8_t*)&cmd.buff[i]);
                UART_printHex((uint8_t)cmd.buff[i]);
                UART_print((uint8_t*)" ");
            }
            UART_print((uint8_t*)"\n\rDATA: ");
            for (i = 0; i < PS1_CTRL_BUFF_SIZE; i++){
                reverse_byte((uint8_t*)&data.buff[i]);
                UART_printHex((uint8_t)data.buff[i]);
                UART_print((uint8_t*)" ");
            }
            UART_print((uint8_t*)"\n\rData done converting");
            
            // Check first command for device selected
            if (cmd.device_select == CMD_SEL_CTRL_1 && cmd.command == CMD_READ_SW){
                // Check ID
                switch(data.id){
                    case ID_GUNCON_CTRL:
                        // Check switch combo
                        switch(data.switches){
                            case KEY_COMBO_GUNCON:
                                reset_long();
                                break;
                        }
                        break;
                    case ID_DIG_CTRL:
                    case ID_ANS_CTRL:
                    case ID_ANP_CTRL:
                    case ID_DS2_CTRL:
                        // Check switch combo
                        switch(data.switches){
                            case KEY_COMBO_CTRL:
                                reset_short();
                                break;
                            case KEY_COMBO_XSTATION:
                                reset_long();
                                break;
                        }
                        break;
                }
            }

            clear_buff((uint8_t*)data.buff, PS1_CTRL_BUFF_SIZE); // clear controller stuff
            clear_buff((uint8_t*)cmd.buff, PS1_CTRL_BUFF_SIZE); // clear controller stuff
    
            data_cnt = 0; // reset counters
            cmd_cnt = 0; // reset counters
            
            PIR1bits.SSP1IF = 0; // clear SPI1 flag
            PIR2bits.SSP2IF = 0; // clear SPI2 flag
            INTCONbits.PEIE = 1; // peripheral interrupt enable
        }
    }
    
    for(;;);
}

/* Reverse byte order 
 * The playstation send data LSb first,
 * but the PIC uses a shift left register
 * so the LSb from the PS1 becomes the MSb of the PIC
*/
void reverse_byte(uint8_t *b) {
   *b = (*b & 0xF0) >> 4 | (*b & 0x0F) << 4;
   *b = (*b & 0xCC) >> 2 | (*b & 0x33) << 2;
   *b = (*b & 0xAA) >> 1 | (*b & 0x55) << 1;
}

/* Clear buffer of size s, aka fill with zero */
void clear_buff(uint8_t *p, uint8_t s){
    uint8_t i;
    for (i = 0; i < s; i++)
        p[i] = 0;
}

/* delay in seconds */
void __delay_s(uint8_t s){
    for (; s > 0; s--)
        __delay_ms(1000);
}


void reset_short(void){
    UART_print((uint8_t*)"\n\rShort Reset successful\n\r");
    // change RESET pin from input to output, logic low (PORT is already 0)
    PS1_TRIS_IO &= ~_BV(PS1_RESET);
    __delay_ms(SHORT_DELAY); // hold reset for 500ms
    // change RESET back to input
    PS1_TRIS_IO |= _BV(PS1_RESET);
    // hold the mcu from resetting too early, just in case
    __delay_s(REBOOT_DELAY);
}

void reset_long(void){
    UART_print((uint8_t*)"\n\rLong Reset successful\n\r");
    // change RESET pin from input to output, logic low (PORT is already 0)
    PS1_TRIS_IO &= ~_BV(PS1_RESET);
    __delay_s(LONG_DELAY); // hold reset for 2s
    // change RESET back to input
    PS1_TRIS_IO |= _BV(PS1_RESET);
    // hold the mcu from resetting too early, just in case
    __delay_s(REBOOT_DELAY);
}

#ifdef DEBUG
/**********************************************************/
/* UART Debug Functions */

/* Initialize UART with TX on output RC3 */
void UART_init(void){
    // SETUP UART
    ANSELCbits.ANSC3 = 0; // TX set to digital I/O
    LATCbits.LATC3 = 0; // set output 0
    TRISCbits.TRISC3 = 0; // TX set to output
    RC3PPSbits.RC3PPS = 0x14; // TX = RC3

    SP1BRGL = 51; // 9615 baud
    SP1BRGH = 0; // 9615 baud
    
    TX1STAbits.SYNC = 0; // Asynch mode
    RC1STAbits.SPEN = 1; // Serial Port enable bit
    TX1STAbits.BRGH = 0; // low speed
    BAUD1CONbits.BRG16 = 0; // 8 bit baud rate
    BAUD1CONbits.SCKP = 0; // Idle state for TX high level
    CLKRCONbits.CLKRDIV = 0; // Fosc
    CLKRCONbits.CLKRDC = 2; // 50% duty cyle
    CLKRCONbits.CLKREN = 1; // Enable CLK reference
    
    TX1STAbits.TXEN = 1; // Enable transmitter  
}

/* Send byte and wait until transfer finished */
void UART_sendByte(uint8_t c){
    TX1REG = c;
    while(!TX1STAbits.TRMT);
}

/* Send string */
void UART_print(uint8_t *str){
    uint8_t i;
    for (i = 0; str[i] != 0 && i < 255; i++)
        UART_sendByte(str[i]);
}

/* Print hex byte in format 0x%02X */
void UART_printHex(uint8_t b){
    uint8_t low_nibble = b & 0x0F;
    uint8_t high_nibble = (b >> 4) & 0x0F;
    
    UART_print((uint8_t*)"0x");
    UART_sendByte(high_nibble >= 10 ? (high_nibble - 10 + 'A') : high_nibble + '0');
    UART_sendByte(low_nibble >= 10 ? (low_nibble - 10 + 'A') : low_nibble + '0');
}
#endif

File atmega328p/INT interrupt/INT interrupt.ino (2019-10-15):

/*
 * Arduino nano reset combo mod POC v2
 * -----------------------------------
 * 
 * IO are setup on PORTB, but can be modified. See PS1_X_IO defines.
 * PB5 - SCK (input, connect to PS1 clock)
 * PB4 - CMD (input, connect to PS1 TX)
 * PB3 - DATA (input, connect to PS1 RX)
 * PB2 - /SS (input, connect to controller 1 select)
 * PB1 - playstation reset (output, connect to reset of parallel port (pin 2))
 * 
 */

#define DEBUG

#if defined(DEBUG)
  #define REBOOT_DELAY 1000
#else
  #define REBOOT_DELAY 1
#endif
 
#define PS1_PIN_IO PIND // IO pin reg used for SS, CMD, DATA and RESET
#define PS1_PORT_IO PORTD // IO port reg used for SS, CMD, DATA and RESET
#define PS1_DIR_IO DDRD // IO dir reg used for SS, CMD, DATA and RESET
#define CLK 2
#define SS 3
#define CMD 4
#define DATA 5
#define RESET 6 // ONly IO that outputs a logic 0

 /* Controller ID */
#define ID_DIG_CTRL 0x5A41 // digital
#define ID_ANP_CTRL 0x5A73 // analog/pad
#define ID_ANS_CTRL 0x5A53 // analog/stick
#define ID_GUNCON_CTRL 0x5A63 // light gun

/* PlayStation Commands */
#define CMD_SEL_CTRL_1 0x01 // select controller 1
#define CMD_SEL_MEMC_1 0x81 // select memory card 1
#define CMD_READ_SW 0x42 // read switch status from controller

/* PlayStation Buff Size */
#define PS1_CTRL_BUFF_SIZE 9 // max size of buffer needed for a controller
#define PORT_BUFF_SIZE 72 // (8 * PS1_CTRL_BUFF_SIZE)

/* Key Combo */
#define KEY_COMBO_CTRL 0xFCF6 // select-start-L2-R2 1111 1100 1111 0110
#define KEY_COMBO_GUNCON 0x9FF7 // A-trigger-B 1001 1111 1111 0111 

/* Key stuff */
#define KEY_PRESSED 0
#define KEY_RELEASED 1

enum Keys{
  SELECT, // 0
  L3,
  R3,
  START, // light gun A
  UP,
  RIGHT,
  DOWN,
  LEFT,
  L2,
  R2,
  L1,
  R1,
  TRIANGLE,
  CIRCLE, // light gun trigger
  CROSS, // light gun B
  SQUARE
};

/* PlayStation Controller Command Union */
union PS1_Cmd{
  uint8_t buff[PS1_CTRL_BUFF_SIZE];
  struct{
    uint8_t device_select; // 0x01 or 0x81
    uint8_t command; // 0x42 for read switch
    uint8_t unused[PS1_CTRL_BUFF_SIZE-2]; // always 0 for controller
  };
};

/* PlayStation Controller Data Union */
union PS1_Ctrl_Data{
  uint8_t buff[PS1_CTRL_BUFF_SIZE]; // buffer to read data
  struct{
    uint8_t unused; // always 0xFF
    uint16_t id; // 0x5Ayz - y = type; z = # of half word
    uint16_t switches; // controller switches
    union{
      // light gun only (8MHz clock counter since hsync)
      uint16_t x_pos; // if 0x0001 then error, check y_pos
      struct{
        uint8_t adc0; // right joy X
        uint8_t adc1; // right joy Y
      };
    };
    union{
      //light gun only (scanlines since vsync
      uint16_t y_pos; // if x_pos = 0x0001 && y_pos = 0x000A => not aimed at screen
      struct{
        uint8_t adc2; // left joy X
        uint8_t adc3; // left joy Y
      };
    };
  };
};

void clear_buff(uint8_t *p, uint8_t s){
  uint8_t i;
  for (i = 0; i < s; i++)
    p[i] = 0;
}

// read 8 bytes -> 1 byte corresponding to bit b
uint8_t convert_buff_to_byte(uint8_t *p, uint8_t b){
  uint8_t i, retval;
  for (i = 0, retval = 0; i < 8; i++){
    if (p[i] & b)
      retval |= _BV(i);
  }
  return retval;
}

uint8_t port[PORT_BUFF_SIZE]; // port buffer
uint8_t bit_cnt; // bit counter

union PS1_Ctrl_Data data;
union PS1_Cmd cmd;

void setup() {
  // Set PORT to inputs and no pull-ups
  PS1_PORT_IO = 0;
  PS1_DIR_IO = 0;

  // ISR setup stuff

  EICRA |= 0x03; // ISC01-ISC00: The rising edge of INT0 generates an interrupt request. -> CLK
  EICRA |= 0x08; // ISC01-ISC00: The falling edge of INT1 generates an interrupt request. -> SS
  EIMSK |= _BV(INT1); // INT1: External Interrupt Request 1 enabled and INT0 disabled
  // Select timer1 normal mode (timer overflow)
  TCCR1A = 0;
  TCCR1B = 2;
  
  SREG |= 0x80; //  I: Global Interrupt Enable

  // -------
  
  DDRB |= _BV(5);
  PORTB |= _BV(5);
  delay(1000); // LED on for 1000ms
  PORTB &= ~_BV(5);
  
  delay(REBOOT_DELAY); // wait 30 seconds after power up
#if defined(DEBUG)
  Serial.begin(115200);
  Serial.println("PlayStation reset mod");
#endif

  // Clear buffer
  clear_buff(cmd.buff, PS1_CTRL_BUFF_SIZE);
  clear_buff(data.buff, PS1_CTRL_BUFF_SIZE);
  clear_buff(port, PORT_BUFF_SIZE);
  // Clear vars
  bit_cnt = 0;
}


// ISR read on rising edge of PD2 using INT0
ISR(INT0_vect){
  port[bit_cnt] = PS1_PIN_IO; // read port
  bit_cnt++;
}

// ISR read on rising edge of PD3 using INT1
ISR(INT1_vect){
  TCNT1 = 65495; // OVF at 65536 (41 clock / 8 cycles)
  TIMSK1 |= _BV(TOIE1);
}

// TMR1 interrupt is triggered when TMR1 overflows
// Check if SS is low for long enough to start reading data, see extra SS pulse after controller data transfer
ISR(TIMER1_OVF_vect){
  if (!(PS1_PIN_IO & _BV(SS))){ // check if SS is still low
    TIMSK1 &= ~_BV(TOIE1); // disable timer interrupt
    EIMSK |= _BV(INT0); // enables external interrupt INT0
  }
}

void loop(){
  if (bit_cnt >= PORT_BUFF_SIZE){
    EIMSK &= ~_BV(INT0); // disable clk interrupt
    EIMSK &= ~_BV(INT1); // disable ss interrupt

    bit_cnt = 0;

    // Convert PORT data to bytes
    uint8_t i;
    for (i = 0; i < PS1_CTRL_BUFF_SIZE; i++){
      cmd.buff[i] = convert_buff_to_byte(&port[i*8], _BV(CMD));
      data.buff[i] = convert_buff_to_byte(&port[i*8], _BV(DATA));
    }
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

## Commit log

2019-06-20 updated code
    some data missing during read, so now it will read until the slave select pin is high (stop transmission) and only then process the read data
2019-06-22 updated code, no interrupt used, only polling
    Using spi interrupt I could only read either data or cmd, but not both. So I tried using external pin interrupt on the clock to read both CMD and DATA, but for some reason I couldn't get it to synch properly.
    Because of that some input status were lost and I couldn't get CMD and DATA to be reliable.
    Now I'm using polling and it seems to work fine, although using a GUNCON doesn't yet work...
2019-06-23 updated code, fixed guncon, fixed reset loop bug
    Found the issue with the guncon, it was a missing break in the switch...
    Also found a reset loop bug when you disconnect the controller from the PS1 after resetting it. The old data was never cleared so the arduino thought it receives a reset command and resets the PS1.
2019-07-07 added box around parallel port reset pin 2
2019-07-07 added debug ifdef here and there for the serial print stuff
2019-10-15 update with all codes and schematic + pcb
    this update contains all files and schematic + pcb I worked on whilst streaming
    [PlayStation 1 Reset Mod.kicad_pcb, PlayStation 1 Reset Mod.sch]
2019-10-15 wrong code and flowchart, added correct code
    [main.c]
2019-10-15 fix arduino ide error
    renamed file and folder without spaces because arduino ide couldn't open the file
    [INT-interrupt.ino]
2019-10-18 Delete playstation_controller.ino
    this one is the arduino nano polling code
2019-10-19 updated schematic and PCB
    fix issues #1, #2, #3, #5
    [PlayStation 1 Reset Mod-B_Cu.gbr, PlayStation 1 Reset Mod-B_Mask.gbr, PlayStation 1 Reset Mod-B_SilkS.gbr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]
2019-10-19 add pictures of schematic and pcb
2019-10-19 remove spi folder for the 328pb
2019-10-19 specify jlc order number location
    this fixes issue #8
    [PlayStation 1 Reset Mod-B_Cu.gbr, PlayStation 1 Reset Mod-B_Mask.gbr, PlayStation 1 Reset Mod-B_SilkS.gbr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]
2019-10-19 added 0603 capacitor
    I've added an extra 0603 capacitor footprint
    [PlayStation 1 Reset Mod.kicad_pcb, PlayStation 1 Reset Mod.sch]
2019-10-19 minor addition to schematic
    added rectangle around the 3 caps on the schematic with text indicating to only install one
    [PlayStation 1 Reset Mod.sch]
2019-10-19 gerber files update
    [PlayStation 1 Reset Mod-B_Cu.gbr, PlayStation 1 Reset Mod-B_Mask.gbr, PlayStation 1 Reset Mod-B_SilkS.gbr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]
2019-10-20 fix code for first release
    issue #9
    [main.c]
2019-10-27 add correct flowchart
2019-10-27 add flowchart images
2019-12-14 switched data and cmd in code, compared to actual hardware pcb
    * Seems like SPI1 and SPI2 were switched on the hardware - fixed in code.
    * I also added the analog pad define back, because that's the one I actually have.
    [main.c]
2020-11-27 gitignore for kicad stuff
2020-11-27 general update
    [PlayStation 1 Reset Mod-B_Cu.gbr, PlayStation 1 Reset Mod-B_Mask.gbr, PlayStation 1 Reset Mod-B_SilkS.gbr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]
2020-11-30 add 555 timer circuit for HW support of the xStation
2020-11-30 added and moved pictures for the 555 timer circuit
2020-12-21 moved arduino stuff into old folder
